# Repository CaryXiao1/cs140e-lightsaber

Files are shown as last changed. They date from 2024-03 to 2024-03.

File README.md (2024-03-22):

Cary Xiao: caryxiao@stanford.edu \
Ekin Tiu: ekintiu@stanford.edu

# CS140E Final Project: Lightsaber!

For our final project, we created a lightsaber prototype. On top of using various lab code to implement certain features, We also implemented a networked bootloader and PWM code to wirelessly send code to the lightsaber and to play sound while polling from the gyroscope, respectively.

Picture of lightsaber we built

As an overview of the lightsaber itself, we designed and 3D-printed a hilt on top of a 24-inch plexiglass tube. We continuously sample from a gyroscope to determine the acceleration of the blade and use that information to determine how loud the sound of the lightsaber should play. Furthermore, we keep track of the direction of acceleration on the lightsaber, and if the direction suddenly changes, we detect that as a collision and briefly change the sound of the lightsaber accordingly.

### Demos

You can find the following demos of the lightsaber between the root folder of this repository and in `tests/`. 

- `gyro-light-audio.c`: This program incorporates the most functionality, using the speaker, gyroscope, and light strip to create a lightsaber demo. Because of the limitations of compute power in the r/pi and because the light strip and sound require very specific timing to correctly function, this demo has a lower sampling rate and some popping artifacts in the 

- `tests/gyro-light.c`: This program does not use the speaker, allowing for us to much more quickly change the brightness of the light strip to correspond to the acceleration in the accelerometer.

- `play_wav_light.c`: This program removes the gyroscope and keeps the light a specific color, allowing us to fully play the .wav file while having the blade lit.

## Networked Bootloader

As seen in the photo above, our goal was to have the lightsaber powered directly by batteries. However, because most of our lab code uses UART to send code to the r/pi to run programs, we either needed to change the bootloader to statically run our lightsaber code, or we would need to send program information wirelessly using the nrf receivers. We decided to go with the latter option, as this would allow us to quickly change the code running on the lightsaber and speed up our debugging process without having to re-compute and replace the `kernel.img` file that's in the SD card of the lightsaber's r/pi.

### Method

To implement the networked bootloader, we decided to use two r/pis: one connected to a computer via UART, and the second powered wirelessly that would get the code. Because of this, we send _two_ programs to the first r/pi using a modified `my-install` called `my-install-relay` (in `final-project/nrf-bootloader/1-unix-side/`). Aside from concatenating the two programs, `my-install-relay` also sends a `uint32_t` directly before the second message to indicate to the first r/pi how long the second program is.

The first r/pi then runs the first program that is sent, `relay.bin` (in `nrf-bootloader/3-relay/`). This program then locates the start of the second program, finds the size of the array, then moves the entire program into the heap before using NRF to send the program and its size to the second r/pi.

Finally, the second r/pi has a modified bootloader (see `nrf-bootloader/2-pi-side/`) that uses NRF instead of UART in `get-code.h`. When the first r/pi sends the code, the second r/pi is able to pick it up, move it to `0x8000`, and then run the program by calling `BRANCHTO(ARM_BASE)`.

### Difficulties

A notable issue we had was figuring out how reliably find the start of the second program on the first r/pi. While this sounds relatively simple by looking at the address `__prog_end__ + 4`. Our current understanding is that `__prog_end__` is set to `ARM_BASE` size of the first program, rounded up to the nearest power of 8, plus 16. However, if the program size is a multiple of 32, then `__prog_end__` is set to `ARM_BASE` plus the size of the first program.

We also had an issue with sending the code to the second r/pi. This is because the second program is initially in "free" memory, which is the reason why we first put it into an allocated space on the heap. However, something we realized is that we needed to first copy it to the stack before allocating the requisite amount from the heap. We found out that if we were to try copying directly from the heap, the system would directly allocate the space we were trying to preserve, zeroing out all the values. Thus, we copied it to the stack, then moved it to the heap so that it would be preserved across function calls.

### Testing and Debugging

To test our nrf bootloading, we created two methods to either test the functionality or debug output:

1. `nrf-bootloader-test.c` (in `nrf-bootloader/3-relay`). This test requires two r/pis with the original UART functionality and uses the first r/pi to send `hello-f.bin` to the second r/pi, which then copies the program into memory and attempts to run it via a `BRANCHTO`. Please see the file for more information about how to run it.

2. `pi-echo.c` (in `nrf-bootloader/1-unix-side`). This modified version of `my-install` enables you to see output from the second r/pi after you change the bootloader to use NRF. We used this program to debug our modified `get-code.c` and ensure that it correctly got programs, ran them, and either restarted or waited for another program.

## I2S

In order to make a "realistic" lightsaber, we wanted to incorporate some aspect of audio. In particular, our goal was to be able to play lightsaber audio noises stored as .WAV files. To do so, we started by trying to implement the I2S protocol detailed in Parthiv's lab (https://github.com/dddrrreee/cs240lx-22spr/tree/main/labs/17-i2s) as the first step. This primarily consisted of initializing I2S by configuring both the I2S peripheral and the clock manager registers in Section 6.3 of the Peripherals manual. We then implemented a `send_sample` function and `read_sample` function aiming to use both TX and RX capabilities of I2S. At this point, we ran into several difficulties.

### Difficulties

1. Our first problem was in debugging the I2S initialization protocol. While we had configured the I2S peripherals correctly, we found that a minor order of operations discrepancy when setting the Clock Manager prevented data from reaching the FIFO.
2. The second and primary difficulty was getting samples to send. After implementing `send_sample`, we found that the TX FIFO was always full, and thus would not send the data to the I2S receiver device.
3. In an attempt to debug with Parthiv, although we did not need the microphone, we tried to get proper readings from RX to distinguish if the issue was with our code, or our hardware. We soon found that the Adafruit microphone I2S setup worked, but the hardware device (RPI Codec Zero) did not give any readings. It did not take long for us to realize the Codec Zero which used a Dialog Semiconductor DA7212 Codec had its own datasheet (obfuscated by the fact that the Codec Zero datasheet was only 5 pages long, we had to figure out what codec it actually used in order to find the real datasheet).

In summary, since even I2S RX would be relatively tricky to figure out with our hardware, we figured getting TX to work with this hardware would be even trickier. In order to avoid a major bottleneck, we discussed with Joe and he suggested using PWM.

## PWM

PWM, or Pulse Width Modulation, is a means of emulating analog IO by setting the ratio (duty cycle) of when a pin is set on vs. off. This would allow us to play a given frequency, and therefore a set tone, on our speaker. We first started off experimenting with this method via software PWM to play a tone, then transitioned to using hardware PWM to play a tone, and eventually playing a `.WAV` file.

### Method

1. To use hardware PWM, we refer to section 9 in the ARM peripherals manual. We first had to set the proper function of PWM pin 18 (`GPIO_FUNC_ALT5`). Then, similar to I2S, we set the GPIO clock manager to operate using the 19.2MHz oscillator. We use a sampling frequency of around 44100 (44.1kHz is common sampling frequency for audio). We control this by setting the `range` of the PWM to `clock_rate` / `sampling_frequency`).
2. We then played a simple tone by writing to the `RNG1` (range) register and the `DAT1` (data) register. `DAT1` / `RNG1` should be a constant PWM frequency, so we are able to create a basic tone. This is done in `tests/play_tone.c`.
3. To get .WAV working, we use a description of the `.WAV` file format online to jump start the process (https://ccrma.stanford.edu/courses/422-winter-2014/projects/WaveFormat/#:~:text=A%20WAVE%20file%20is%20often,form%20the%20%22Canonical%20form%22.) We understood that getting `.WAV` to run should consist of iterating through each `.WAV` sample, and sending the corresponding frequency to the `PWM_FIFO`. For this, we additionally enable FIFO in the PWM `CTL` register, and write to `FIF1`. The first test is in `tests/play_wav.c`. Once we were able to play on wav file, we were able to use this code to bring everything together.

### Difficulties

1. The first difficulty was when setting PWM Peripherals registers, and understanding which mode to use. Thw PWM controller has two submodes where `MSEN=0` and `MSEN=1`. We were initially using `MSEN=0` as the this uses the default PWM algorithm. When reading through the datasheet, it was hard to distinguish the difference between the modes. One seemed to use N/M as the duty cycle, whereas the other described the same duty cycle using different letters M/S. For this, a friend who had taken the class last year was able to help out and suggested trying `MSEN=1`.
2. Playing the audio at the same time as the neopixel lights and gyroscope. During our first iteration, we tried to incorporate sending samples to the speaker within the same while loop as our gyro and setting lights. The issue here was that gyro and lights would take extra cycles, and since PWM is dependent on the timing of setting items in FIFO, we would get white noise. A semi-solution was to split the audio file into chunks, and play each chunk at a time. The tradeoff was an evident popping noise. Our solution to the popping was to increase the volume of the original .wav file so that the popping was less apparent. This gave it the illusion of concurrency!

Special shoutout to Joe Tan and Daniel Zamoschin (student in last year's class) who took the time to help us get through these difficulties.

## Designing the Hilt

While this is not necessarily related to computer systems, we did spend a non-negligible amount of time CADing and 3D-printing the hilt that housed all our devices. To see .obj and .stl files exported from Fusion 360

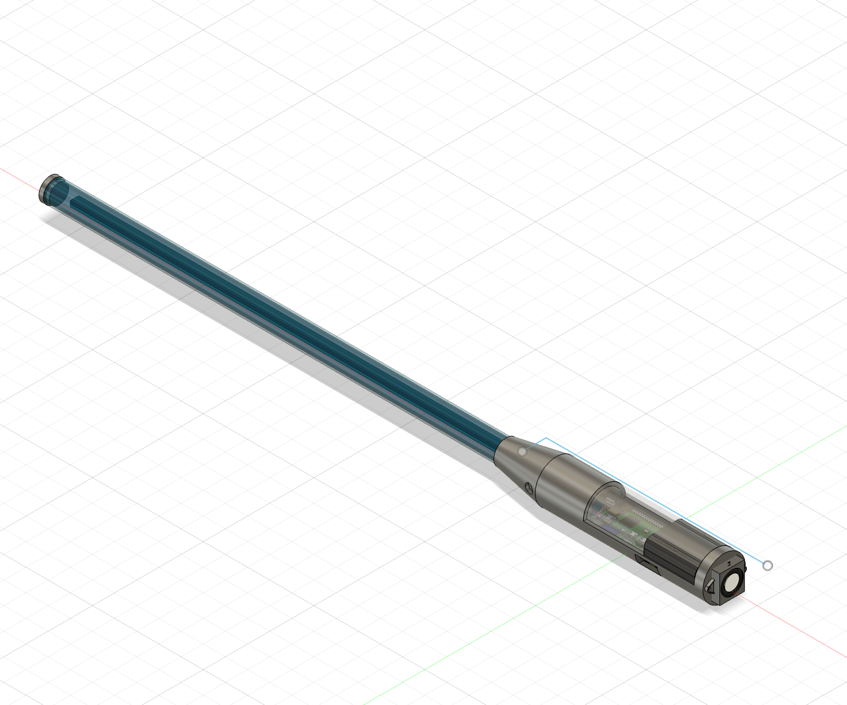
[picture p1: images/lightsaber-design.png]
Fusion 360 screenshot of lightsaber hilt


## Putting it Together

After implementing the individual components, we had to create a script that would incorporate all the APIs we had written thus far for each of the protocols. In particular, using the accelerometer and gyro to influence the light output of our neopixel light strip, while simulatenously getting audio to play.

### Method

1. First, get `tests/gyro-light.c` to work. We decided to tackle this in pairwise chunks. Our first pair was getting gyro and light to work concurrently. Our idea was to use the magnitude of the acceleration vector. After normalizing acceleration vectors, we use this proportion out of 255 to get a light value for the neopixels. This seems to work well.
2. `tests/play_wav_light.c` Plays the light and the audio at the same time, but at a constant light intensity.
3. Finally, `gyro-light-audio.c` is our main script, which plays the audio, gyro and light at the same time. See `pwm` section for details about implementation.

# Additional Protocols

## I2C

Use repurpose code from the `labs/11-imu-i2c` lab.

## WS2812 (Neopixel)

Followed the lab in `extensions-devices/3-ws2812` to interface with the light strips.

## FAT32

Repurposed code from `labs/19-fat32-readonly` in order to read `.WAV` files from our filesystem into memory.

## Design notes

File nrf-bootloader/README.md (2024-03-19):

# NRF Bootloader

This is a modified version of lab 17, taking and modifying the `get-code.h` file from lab 7 to enable wireless code transeiving.

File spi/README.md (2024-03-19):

# Serial Peripheral Interface (SPI) Implementation

TODO!

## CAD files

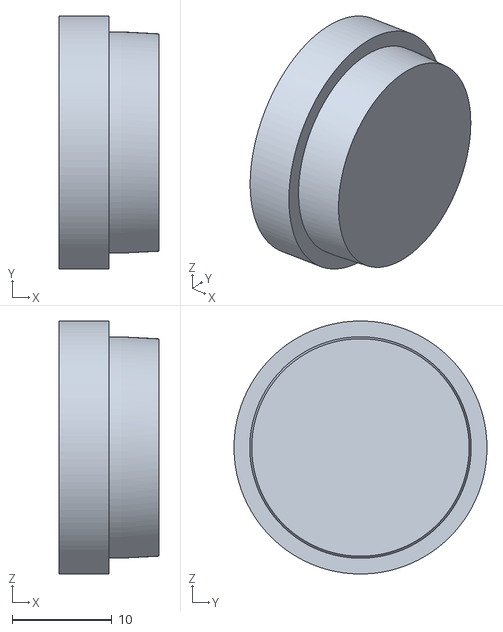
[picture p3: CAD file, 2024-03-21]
hilt-design/lightsaber_top_cover.stl
10.0 x 25.4 x 25.4

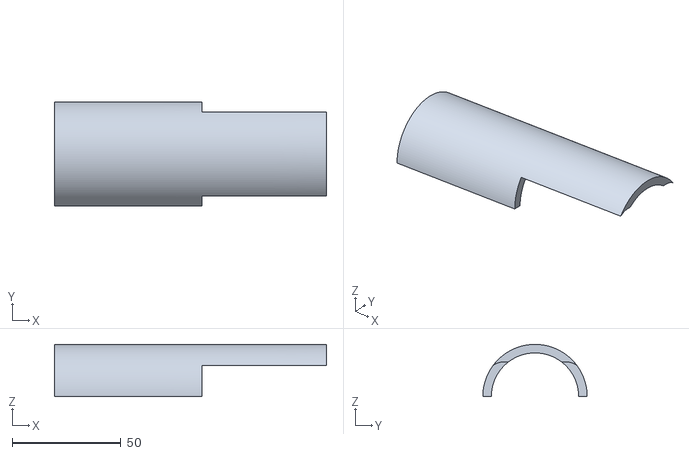
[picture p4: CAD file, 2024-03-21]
hilt-design/hilt-cover-shortened.stl
125.0 x 48.0 x 24.0

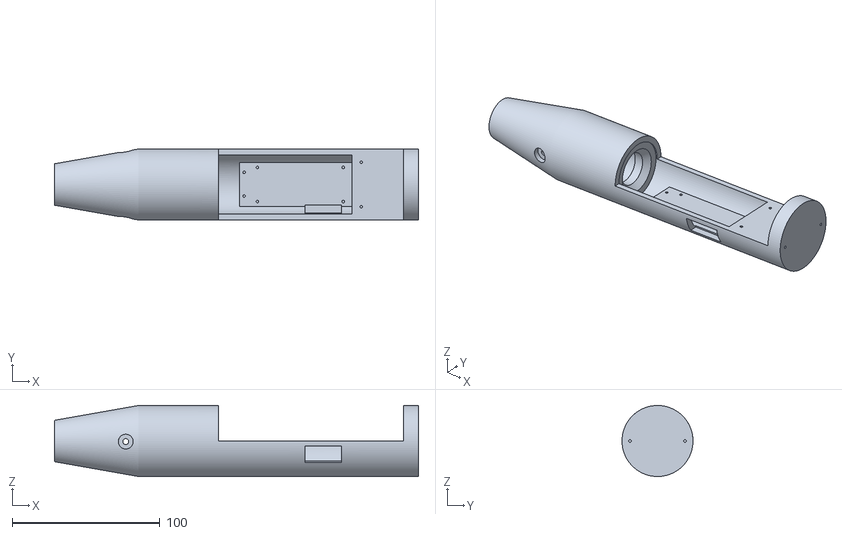
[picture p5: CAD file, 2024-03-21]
hilt-design/lightsaber-hilt-shortened.stl
246.0 x 48.0 x 48.0

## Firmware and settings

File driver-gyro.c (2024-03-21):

// engler: simplistic mpu6050 gyro driver code, mirrors
// <driver-accel.c>.  
//  1. initializes gyroscope,
//  2. prints N readings.
//
// as with <driver-accel.c>:
//   - <mpu-6050.h> has the interface description.
//   - <mpu-6050.c> is where your code will go.
//
//
// Obvious extension:
//  0. validate the 'data ready' matches what we set it to.
//  1. device interrupts.
//  2. bit bang i2c
//  3. multiple devices.
//  4. extend the interface to give more control.
//  
//
// KEY: document why you are doing what you are doing.
//  **** put page numbers for any device-specific things you do ***
//  **** put page numbers for any device-specific things you do ***
//  **** put page numbers for any device-specific things you do ***
//  **** put page numbers for any device-specific things you do ***
//  **** put page numbers for any device-specific things you do ***
//  **** put page numbers for any device-specific things you do ***
//  **** put page numbers for any device-specific things you do ***
// 
// also: a sentence or two will go a long way in a year when you want 
// to re-use the code.
#include "rpi.h"
#include "mpu-6050.h"

void notmain(void) {
    delay_ms(100);   // allow time for i2c/device to boot up.
    i2c_init();
    delay_ms(100);   // allow time for i2c/dev to settle after init.

    // from application note.
    uint8_t dev_addr = 0b1101000;

    enum { 
        WHO_AM_I_REG      = 0x75, 
        WHO_AM_I_VAL = 0x68,       
    };

    uint8_t v = imu_rd(dev_addr, WHO_AM_I_REG);
    if(v != WHO_AM_I_VAL)
        panic("Initial probe failed: expected %b (%x), have %b (%x)\n", 
            WHO_AM_I_VAL, WHO_AM_I_VAL, v, v);
    printk("SUCCESS: mpu-6050 acknowledged our ping: WHO_AM_I=%b!!\n", v);

    // hard reset: it won't be when your pi reboots.
    mpu6050_reset(dev_addr);

    // part 2: get the gyro working.
    gyro_t g = mpu6050_gyro_init(dev_addr, gyro_500dps);
    assert(g.dps==500);

    for(int i = 0; i < 100000; i++) {
        imu_xyz_t xyz_raw = gyro_rd(&g);
        uint32_t g_const = 25000; // 25000 for swing, TODO: figure out the tracking of collisions
        // output("reading gyro %d\n", i);

        // get length of overall movement from 3 component
        uint32_t overall = xyz_raw.y * xyz_raw.y + xyz_raw.z * xyz_raw.z; // xyz_ra w.x * xyz_raw.x + 
        if (overall >= g_const * g_const) {
            printk("swing! id=%d\n", i);
            
        }


        // xyz_print("\traw", xyz_raw);
        // xyz_print("\tscaled (milli dps)", gyro_scale(&g, xyz_raw));
        delay_ms(20);
    }
}

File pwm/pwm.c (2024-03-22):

#include "rpi.h"
#include "pwm.h"

// Nominal clock frequencies
#define F_OSC   19200000
#define F_PLLD 500000000
#define F_AUDIO 1000000


#define BM_PASSWORD 0x5A000000

#define CM_PWMCTL 0x201010A0
#define CM_PWMDIV 0x201010A4

#define CM_ENABLE  (1 << 4)
#define CM_KILL    (1 << 5)
#define CM_BUSY    (1 << 7) 
#define CM_FLIP    (1 << 8)
#define CM_MASH0   (0 << 9)
#define CM_MASH1   (1 << 9)
#define CM_MASH2   (2 << 9)
#define CM_MASH3   (3 << 9)


#define PWM_CTL    0x2020C000
#define PWM_STATUS 0x2020C004
#define PWM_DMAC   0x2020C008
#define PWM_FIFO   0x2020C018

#define PWM0_RANGE 0x2020C010
#define PWM0_DATA  0x2020C014

#define PWM1_RANGE 0x2020C020
#define PWM1_DATA  0x2020C024

#define PWM0_ENABLE      0x0001
#define PWM0_SERIAL      0x0002
#define PWM0_REPEATFF    0x0004
#define PWM0_OFFSTATE    0x0008
#define PWM0_REVPOLARITY 0x0010
#define PWM0_USEFIFO     0x0020
#define PWM0_MARKSPACE   0x0080

#define PWM1_ENABLE      0x0100
#define PWM1_SERIAL      0x0200
#define PWM1_REPEATFF    0x0400
#define PWM1_OFFSTATE    0x0800
#define PWM1_REVPOLARITY 0x1000
#define PWM1_USEFIFO     0x2000
#define PWM1_MARKSPACE   0x8000

#define PWM_CLEARFIFO    (1 << 6)



/*
 * this version is fragile. because divisor is 12-bits
 * we need to change the pwm clock depending on the input
 * frequency.
 */
void play_tone(int freq) {
    if (freq == 0) {
        pwm_disable(0);
        pwm_disable(1);
        return;
    }

    // Assumes pwm init and gpio pin setup

    pwm_set_clock( F_AUDIO);
    delay_ms(2);

    pwm_set_mode( 0, PWM_MARKSPACE);
    pwm_set_fifo( 0, 0 );
    pwm_enable( 0 );

    pwm_set_mode( 1, PWM_MARKSPACE);
    pwm_set_fifo( 1, 0 );
    pwm_enable( 1 );

    // assumes pwm_clock(F_AUDIO)
    int divisor = F_AUDIO / freq;
    int divisor2 = divisor / 4;

    pwm_set_range(0,  divisor);
    pwm_set_width(0,  divisor2);

    pwm_set_range(1,  divisor);
    pwm_set_width(1,  divisor2);

}

void pwm_init(void)
{
    //pwm_set_clock( F_OSC );
    //pwm_set_mode( 0, PWM_MARKSPACE );
    //pwm_set_fifo( 0, 0 );
    //pwm_set_mode( 1, PWM_MARKSPACE );
    //pwm_set_fifo( 1, 0 );
}

void set_sample_rate(int sample_rate) {
    pwm_disable(0);
    pwm_disable(1);
    pwm_clear_fifo();
    delay_ms(2);

    audio_init(sample_rate);

}

void audio_init(int sample_rate) {
    // sample_rate = 44.1kHz
    gpio_set_function(18, GPIO_FUNC_ALT5);
    gpio_set_function(12, GPIO_FUNC_ALT0);
    delay_ms(2);

    pwm_init();

//    pwm_set_clock( 19200000 / CLOCK_DIVISOR ); // 9600000 Hz

    int clock_rate = 19200000 / 2; // 9600000 Hz
    int range = clock_rate / sample_rate; //  clock_rate = output frequency
    pwm_set_clock(clock_rate); // 
    delay_ms(2);

    pwm_set_mode( 0, PWM_SIGMADELTA );
    pwm_set_mode( 1, PWM_SIGMADELTA );

    pwm_set_fifo(0, 1);
    pwm_set_fifo(1, 1);

    // enable both channels
    pwm_enable(0);
    pwm_enable(1);

    // pwm range is 1024 cycles
    pwm_set_range(0, range); // range is (9.6MHz / 44.1kHz)
    pwm_set_range(1, range); 
    // FIFO data is x / (9.6MHz / 44.1kHz = 217.687075Hz)
    delay_ms(2);
}

/*
 * pwm frequency in Hz = 19 200 000 Hz / pwmClock / pwmRange
 * pwmClock is really a divider (e.g., if we want a divider of 16, we
 * should pass in a freq of 19 200 000 / 16)
 */
void pwm_set_clock(int freq) {
    // freq = 9600000 Hz 
    int timer = F_OSC; // Use the fastest clock, 19.2MHz oscillator
    int source = 1;

    // divisor = 2, divisor = divi
    int divisor  = timer / freq; // for freq=16, divisor = 1.2e6
    int fraction = (timer % freq) * 4096 / freq; // fraction = 0
    // max fraction is 2^12 = 4096
    int mash = fraction ? CM_MASH1 : CM_MASH0;

    // output frequency will be (timer / divisor) = freq = 9.6MHz
    if( mash == CM_MASH0 && divisor < 1 )
        divisor = 1;
    else if( mash == CM_MASH1 && divisor < 2 )
        divisor = 2;
    if (divisor > 4095)
        divisor = 4095;

    // Set fraction, clamp fraction
    if (fraction > 4095)
        fraction = 4095;

    int pwm = GET32(PWM_CTL); // save pwm control register

    // turn off pwm before changing the clock
    PUT32(PWM_CTL, 0);

    PUT32(CM_PWMCTL, BM_PASSWORD | source) ;          // turn off clock
    while (GET32(CM_PWMCTL) & CM_BUSY) ;     // wait for clock to stop

    PUT32(CM_PWMDIV, BM_PASSWORD | (divisor << 12) | fraction);
    PUT32(CM_PWMCTL, BM_PASSWORD | CM_ENABLE | mash | source);
    PUT32(PWM_CTL, pwm); // restore pwm control register
}


void pwm_enable(int chan) 
{
    int ra = GET32(PWM_CTL);
    if (chan == 0) {
        ra |=  PWM0_ENABLE;
    }
    if (chan == 1) {
        ra |=  PWM1_ENABLE;
    }
    PUT32(PWM_CTL, ra);
}

void pwm_disable(int chan) 
{
    int ra = GET32(PWM_CTL);
    if (chan == 0) {
        ra &=  ~PWM0_ENABLE;
    }
    if (chan == 1) {
        ra &=  ~PWM1_ENABLE;
    }
    PUT32(PWM_CTL, ra);
}


void pwm_set_mode(int chan, int markspace) {
    int ra = GET32(PWM_CTL);
    if (chan == 0) {
        if (markspace) {
            ra |=  PWM0_MARKSPACE;
        } else {
            ra &= ~PWM0_MARKSPACE;
        }
    }
    if (chan == 1) {
        if (markspace) {
            ra |=  PWM1_MARKSPACE;
        } else {
            ra &= ~PWM1_MARKSPACE;
        }
    }
    PUT32(PWM_CTL, ra);
}


void pwm_set_fifo(int chan, int usefifo) {
    int ra = GET32(PWM_CTL);
    if (chan == 0) {
        if (usefifo) {
            ra |=  PWM0_USEFIFO;
        } else {
            ra &= ~PWM0_USEFIFO;
        }
    }
    if (chan == 1) {
        if (usefifo) {
            ra |=  PWM1_USEFIFO;
        } else {
            ra &= ~PWM1_USEFIFO;
        }
    }
    PUT32(PWM_CTL, ra);
}

void pwm_clear_fifo(void)
{
    unsigned ra = GET32(PWM_CTL);
    PUT32(PWM_CTL, ra | PWM_CLEARFIFO);
}

/*
 * range should be between 0 and 4095
 */
void pwm_set_range(int chan, int range) {
    if (chan == 0) {
        PUT32(PWM0_RANGE, range);
    }
    if (chan == 1) {
        PUT32(PWM1_RANGE, range);
    }
}

void pwm_set_width(int chan, int width) {
    if (chan == 0) {
        PUT32(PWM0_DATA, width);
    }
    if (chan == 1) {
        PUT32(PWM1_DATA, width);
    }
}

unsigned pwm_get_status(void) {
    return GET32(PWM_STATUS);
}

void pwm_write(int value) {
    PUT32(PWM_FIFO, value);
}

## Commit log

2024-03-19 fix headers and certify start addr, size of 2nd program in relay.c
    [nrf-driver.c]
2024-03-20 fix alignment issue in relay
2024-03-20 fix smaller issue in relay
2024-03-20 relay now attempts to use nrf
2024-03-20 fix relay.c
2024-03-21 add hilt design files
    [hilt-cover-shortened.stl, lightsaber-hilt-shortened.stl, lightsaber_top_cover.stl]
2024-03-21 wip: add light intensity controlled by gyro
2024-03-21 wip: change pin to 18
2024-03-21 wip: add i2s and pwm to readme
2024-03-21 wip: add more pwm to readme
2024-03-22 wip: finish pwm section
2024-03-22 wip: add comments to audio pwm
